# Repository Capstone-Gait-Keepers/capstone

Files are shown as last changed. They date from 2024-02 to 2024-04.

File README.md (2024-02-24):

# Capstone :)

## Folder Structure
- fw: Firmware. Embedded software a.k.a things that run on micros
- data_analysis: All postprocessing or data capturing. Currently includes simulations as well
- datasets: All recorded data
- frontend: Hosts a Vue app
- backend: Hosts a flask App

# Running the Project
## Firmware Setup
1. Add `https://arduino.esp8266.com/stable/package_esp8266com_index.json` as an additional board manager URL (in preferences)
2. Install `esp8266timerinterrupt` library
3. Select NodeMCU 1.0 as the board type
4. Compile and run :)

## Frontend Setup
1. Install [Node](https://nodejs.org/en)
   - Check box to automatically install all dependencies, if applicable 
   - Verify installation with `npm -v`
2. Add `frontend/.env` file (get it from Dan)
3. Install dependencies and run a local development server:
```
cd frontend
npm install
npm run dev
```

## Backend
### Installations
#### Locally hosted Backend
- Python 3.11.6 virtual environment (`python3.11 -m venv ./path/to/venv/folder`)
- Install dependencies in backend_requirements.txt
- `backend/.env` file from cybersecurity risk thread in slack

#### Locally hosted DB
- PostgreSQL https://www.postgresql.org/download/
    - Install with default settings 
- Docker https://docs.docker.com/desktop/install/windows-install/
    - PostgreSQL image 
        - Run 'docker pull postgres' to download the image 
        - Documentation: https://hub.docker.com/_/postgres
- DBeaver https://dbeaver.io/download/
    - or other DB IDE of choice, setup instructions may vary 
    - pgAdmin4 comes with the PostgreSQL installation but I found creating a connection confusing 

### Running the Backend
- If locally hosting the DB, point the `.env` file to the local url
- Run app.py, app will be live locally
- Run client.py in dedicated terminal to test

### Running the Database
#### Docker
- in terminal, run 'docker run --name some-postgres -e POSTGRES_PASSWORD=mysecretpassword -d postgres'
    - name = name of image, your choice
    - password = set a password, remember it preferably
    - 'd' means it runs in 'detached mode'
- To run your image, the command is 'docker start some-postgres' where some-postgres is your image name
- To stop your image, the command is 'docker stop some-postgres'

#### Connecting PostgreSql locally with Docker Image
Make sure your docker image is running first!

Tutorial link that I found helpful: https://www.youtube.com/watch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  (starts from Docker installation)
1. Open DBeaver
2. 'Create new connection' by clicking plug button in top left
3. Select PostgreSQL -> Next
4. Host: localhost
5. Port: 5432
6. Database: postgres
7. password: the password you set with the docker image
8. Click 'Test Connection' -> you should see a success image.
9. If connection works, hit finish

#### FLASK APP
- Run app.py, app will be live locally
- Run client.py in dedicated terminal to test
- Terminal should display success message + data should appear in 'sensors' db table

## Current backend + DB status:
- POST API endpoint set up for testing purposes in Flask app
- PostgreSQL locally hosted on Docker image
- Can receive data from POST endpoint and push it to said database.

### Viewing Frontend Pages from Flask
If you'd like to host the frontend using Flask, you need to build a static version of the frontend.
```
cd frontend
npm run build
```

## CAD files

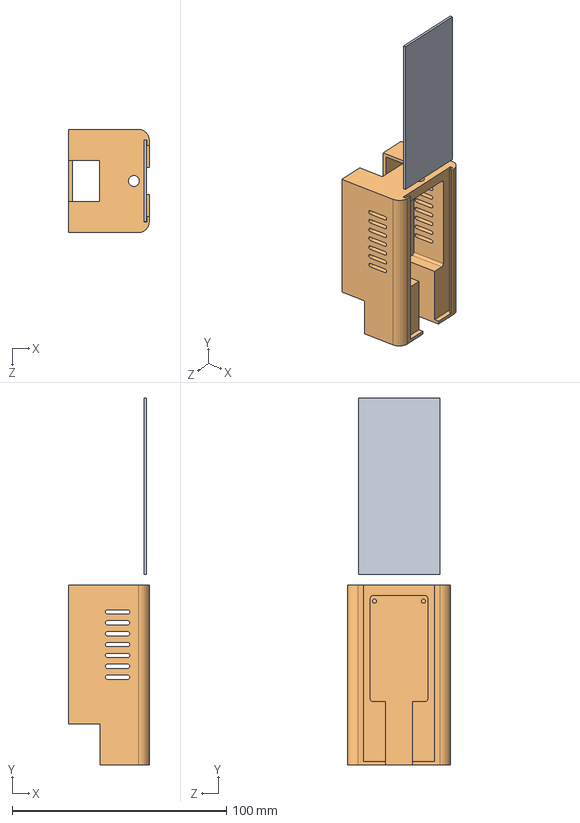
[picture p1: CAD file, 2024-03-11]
casing/Adapter_V2.SLDASM
37.7 x 171.5 x 48.3 mm
Adapter_Case_V2
Adapter_Cover

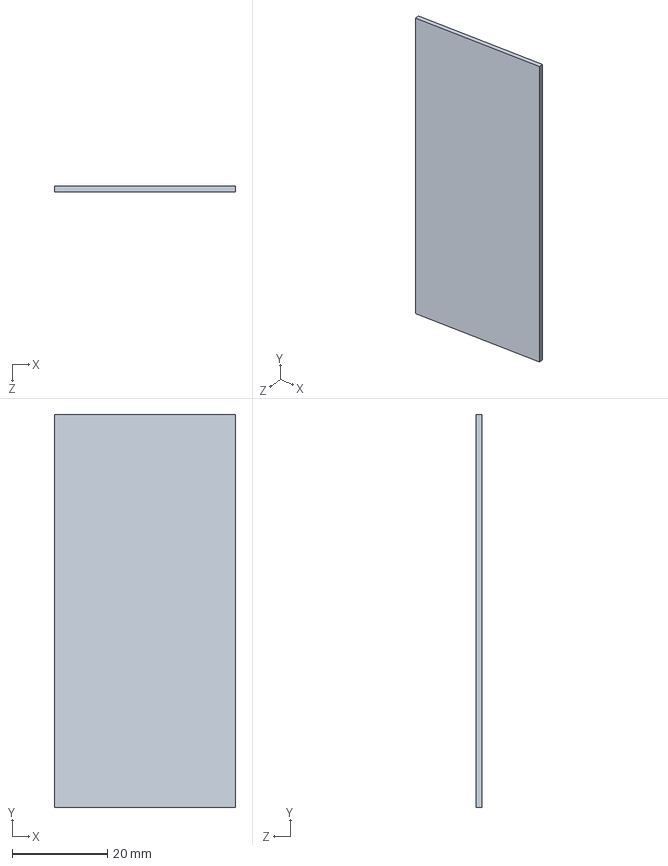
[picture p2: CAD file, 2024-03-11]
casing/Adapter_Cover.SLDPRT
38.1 x 82.5 x 1.27 mm

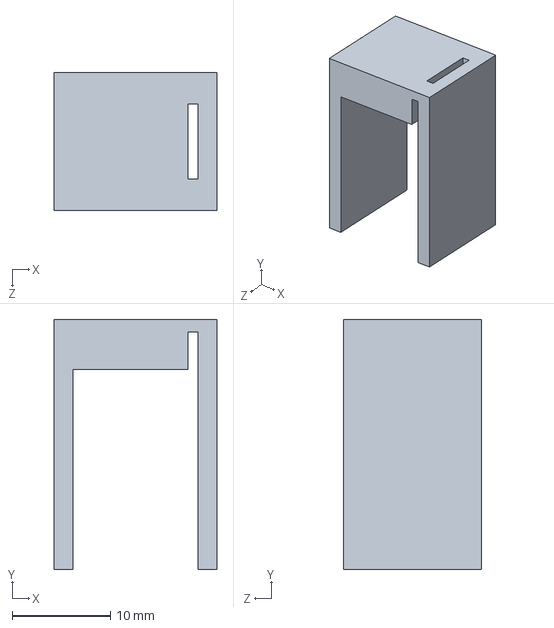
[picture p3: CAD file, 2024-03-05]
casing/V1/Sensor_Case_V1.SLDPRT
16.5 x 25.4 x 14.0 mm

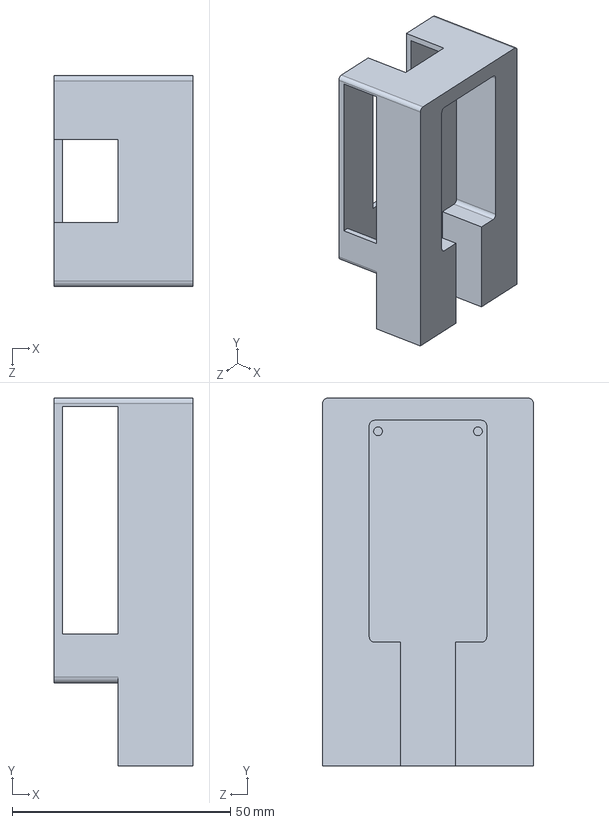
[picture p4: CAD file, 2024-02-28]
casing/V1/Adapter_Case_V1.SLDPRT
31.8 x 84.2 x 48.3 mm

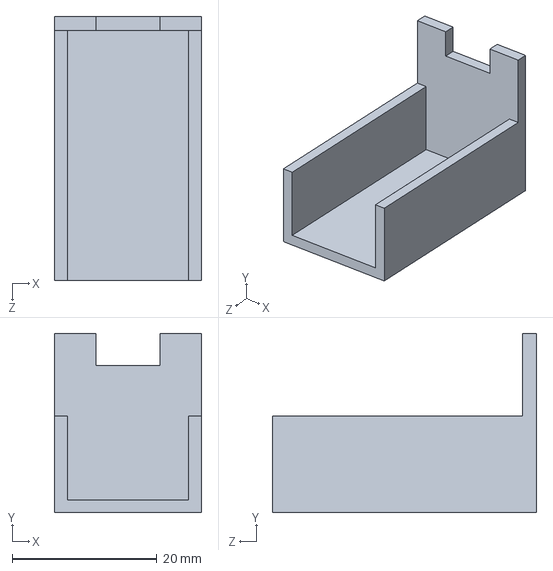
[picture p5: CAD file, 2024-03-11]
casing/Sensor_Cover_V2.SLDPRT
20.3 x 24.8 x 36.4 mm

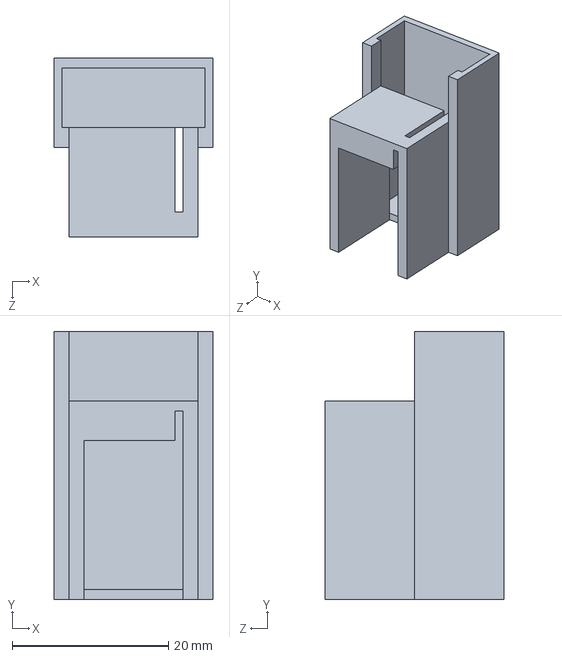
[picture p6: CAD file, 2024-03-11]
casing/Sensor_Case_V2.SLDPRT
20.3 x 34.3 x 22.9 mm

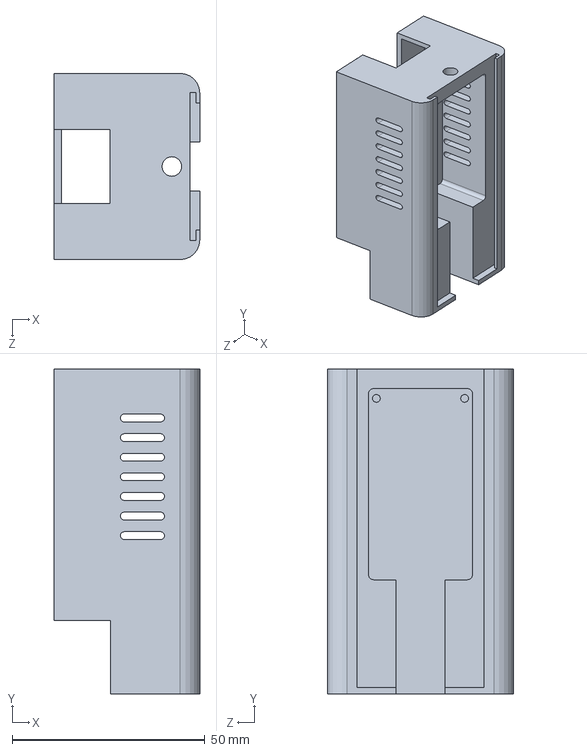
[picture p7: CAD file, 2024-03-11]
casing/Adapter_Case_V2.SLDPRT
37.7 x 84.2 x 48.3 mm

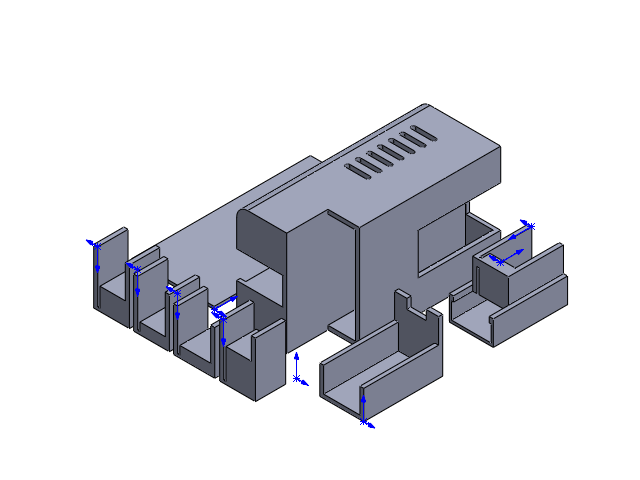
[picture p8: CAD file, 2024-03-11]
casing/V2_Print.SLDASM
Adapter_Cover
Adapter_Case_V2
Sensor_Case_V1_Support0.6
Sensor_Case_V1_Height0.8
Sensor_Case_V1_Height0.9
Sensor_Case_V1_Support0.4
Sensor_Case_V2
Sensor_Cover_V2

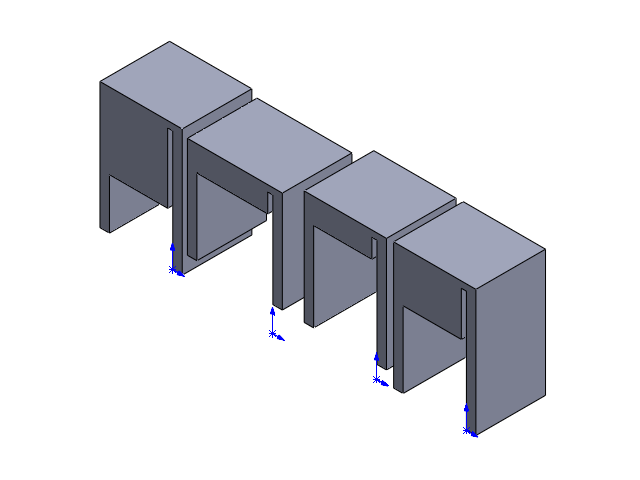
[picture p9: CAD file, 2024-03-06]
casing/SensorCaseVariations.SLDASM
Sensor_Case_V1_Support0.6
Sensor_Case_V1_Height0.8
Sensor_Case_V1_Height0.9
Sensor_Case_V1_Support0.4

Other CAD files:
casing/SensorCaseVariations.STL
casing/Sensor_Cover_V2.STL
casing/V1/Adapter_Case_V1.STL
casing/V1/Sensor_Case_V1.STL
casing/V2_Print.STL

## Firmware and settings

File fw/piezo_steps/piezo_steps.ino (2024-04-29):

#include <Wire.h>
#include <Adafruit_Sensor.h>
#include <Adafruit_BNO055.h>
#include <utility/imumaths.h>
#include "ESP8266TimerInterrupt.h"              //https://github.com/khoih-prog/ESP8266TimerInterrupt

/*
   Connections
   ===========
    Piezo is setup with amplifying circuit:
    Sense wire from piezo to A0 (ADC0)
    Ground
    3v
*/

// Adafruit_BNO055 bno = Adafruit_BNO055(55, 0x28);
ESP8266Timer i_timer;  // Hardware Timer

#define PIEZO_PIN A0 // A0 (ADC0)
#define SAMPLE_RATE 500 // Hz
#define MICROSECONDS 1000000 // Microseconds in a second

#define USER_ID 821094 // User ID for this device

#define INTERRUPT_INTERVAL_US (1000000/SAMPLE_RATE) // Interval between samples in microseconds
#define START_BUFFER_TIME 0.1 // Size of buffer to store acceleration data prior to first step (in seconds)
#define END_BUFFER_TIME 2 // Size of buffer to store acceleration data after last step (in seconds)
#define START_BUFFER_SAMPLES int(START_BUFFER_TIME * SAMPLE_RATE)  // In samples
#define END_BUFFER_SAMPLES END_BUFFER_TIME * SAMPLE_RATE // Number of bad samples to save before stopping saving data
#define CALIBRATION_TIME 6 // Time to run calibration for (in seconds)

// #define AMP_THRESHOLD 0.5 // Threshold for amplitude of acceleration data to be considered "good" (in m/s^2)
float amp_threshold = 0.03; // Threshold for amplitude of acceleration data to be considered "good" (in m/s^2)

volatile bool start_sampling = false; // Flag to indicate if a new sample should be taken based on timer interrupt

bool calibration_flag = false; // Flag to indicate if the device is in calibration mode
bool wifi_status = false; // Flag to indicate if the device is connected to wifi

float sensor_data_buffer[START_BUFFER_SAMPLES]; // Circular buffer to store acceleration data
int start_buffer_index = 0; // Index of circular buffer
String post_data = ""; // String to store data to be sent to backend server
bool save_sample_flag = false; // Flag to indicate if a sample should be saved to post_data
bool post_data_ready = false; // Flag to indicate if post_data is ready to be sent to backend server
int end_buffer_length = 0; // Counter to logic to stop saving data to post_data if too many bad samples are received
bool good_sample = false; // Flag to indicate if a sample is considered "good" (above threshold)


// Interrupt handler for timer
void ICACHE_RAM_ATTR TimerHandler(void)
{
  if (start_sampling) {
    Serial.println("ERROR: PREVIOUS SAMPLED WAS NOT FINISHED");
  }
  start_sampling = true;
}

void update_circular_buffer(float accel_z) {
  // Update circular buffer
  sensor_data_buffer[start_buffer_index] = accel_z;
  good_sample = abs(accel_z) > amp_threshold;
  start_buffer_index++;
  start_buffer_index %= START_BUFFER_SAMPLES; 
  // Move to the next index, modulus handle wraparound
}

void save_circular_buffer() {
  Serial.println("Begin saving data");
  post_data += "{\"sensorid\":\"" + String(USER_ID) + "\",\"ts_data\":[";
  for (int i = start_buffer_index; i < start_buffer_index + START_BUFFER_SAMPLES; i++) {
      post_data += String(sensor_data_buffer[i % START_BUFFER_SAMPLES]) + ",";
  }
  save_sample_flag = true;
}
void save_sample(float accel_z) {
  post_data += String(accel_z) + ",";
}

void stop_saving_samples() {
  save_sample_flag = false;
  post_data_ready = true;
  end_buffer_length = 0;
}

void running_mode() {
  if (start_sampling) 
  {
    float accel_z = getVerticalAcceleration(); // Get z component of acceleration
    start_sampling = false; // Reset flag for interrupt handler

    update_circular_buffer(accel_z); // Update circular buffer with new sample
    // if sample is considered good (above threshold), save buffer to string and start saving data to post_data
    if (good_sample && !save_sample_flag) {
      save_circular_buffer();
      led_on();
    }
    if (good_sample && save_sample_flag) {
      save_sample(accel_z);
      end_buffer_length = 0;
    }
    if (!good_sample && save_sample_flag) {
        if (end_buffer_length < END_BUFFER_SAMPLES) {
          save_sample(accel_z);
          end_buffer_length++;
        } 
        else {
          stop_saving_samples(); // Stop saving samples & reset flags if too many samples don't meet threshold
        }
      }
    if (post_data_ready) {
        Serial.println("POST DATA READY:");
        i_timer.disableTimer();
        led_off();
        // remove last comma if it exists
        if (post_data.endsWith(",")) {
          post_data.remove(post_data.length() - 1);
        }
        post_data += "]}";  // add the end of the json format
        send_data(&post_data);
        post_data_ready = false;
        post_data = "";
        i_timer.enableTimer();
    }
  }
}

double getVerticalAcceleration() {
  int sensorValue = analogRead(PIEZO_PIN);
  double voltage = sensorValue * (3.3 / 1023.0);
  double acceleration = (voltage - 2.04); // account for DC offset (manual)
  return acceleration;
}


void setup(void)
{
  Serial.begin(115200);
  delay(100);
  Serial.println("FW: Step Detection\n");

  pinMode(LED_BUILTIN, OUTPUT);     // Initialize the LED_BUILTIN pin as an output
  pinMode(PIEZO_PIN, INPUT);
  digitalWrite(LED_BUILTIN, HIGH);   // Turn the LED on by making the voltage LOW
  wifi_status = initialize_wifi();

  Serial.print("Sample Rate (Hz): ");
  Serial.println(SAMPLE_RATE);
  i_timer.attachInterruptInterval(INTERRUPT_INTERVAL_US, TimerHandler);
  i_timer.enableTimer();
}

void loop(void)
{
  if (!wifi_status) {
    sos_mode();
  }
  if (calibration_flag) {
    calibration_mode();
  }
  else {
    running_mode();
  }
}

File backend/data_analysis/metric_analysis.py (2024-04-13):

import numpy as np
import pandas as pd
import plotly.express as px
import sys
from plotly.subplots import make_subplots
from plotly import graph_objects as go
from typing import List, Tuple, Optional, Iterable
from logging import Logger, getLogger, StreamHandler, FileHandler, Formatter

from data_types import Recording, RecordingEnvironment, SensorType, get_optimal_analysis_params
from metrics import Metrics
from step_detection import DataHandler, StepDetector, TimeSeriesProcessor


class RecordingProcessor:
    """Collection of methods for processing recordings"""
    def __init__(self) -> None: ...

    @staticmethod
    def get_steps_from_truth(rec: Recording, step_duration=0.4, shift_percent=0.2, align_peak=True, plot=False) -> List[np.ndarray]:
        """
        Uses the source of truth to parse the accelerometer data pertaining to steps
        """
        proc = TimeSeriesProcessor(rec.env.fs)
        offset = int(shift_percent * rec.env.fs / 2)
        window_size = proc.timestamp_to_index(step_duration)
        step_measurements = []
        for event in rec.events:
            if event.category == 'step':
                start = max(0, proc.timestamp_to_index(event.timestamp) - offset)
                step_data = rec.ts[start : start+window_size]
                if len(step_data) != window_size:
                    raise ValueError(f"Step data is the wrong size: {len(step_data)} != {window_size} ({len(rec.ts)=}, {start=}, {start+window_size=})")
                if align_peak:
                    energy = proc.get_energy(step_data, step_duration / 5)
                    start += np.argmax(energy) - offset
                    step_data = rec.ts[start : start+window_size]
                if start + window_size > len(rec.ts):
                    continue
                if len(step_data) != window_size:
                    raise ValueError(f"Step data is the wrong size: {len(step_data)} != {window_size}")
                step_measurements.append(step_data)
        if plot:
            fig = go.Figure()
            fig.update_layout(title="Step Data")
            timestamps = np.linspace(0, step_duration, len(step_measurements[0]))
            for step in step_measurements:
                fig.add_scatter(x=timestamps, y=proc.get_energy(step, step_duration/2))
            fig.show()
        return step_measurements

    @staticmethod
    def get_noise(rec: Recording, window_duration=0.2, plot=False) -> np.ndarray:
        """
        Find the noise floor of the accelerometer data
        """
        if len(rec.events) == 0:
            return rec.ts
        proc = TimeSeriesProcessor(rec.env.fs)
        first_event = rec.events[0].timestamp - window_duration
        noise = rec.ts[:proc.timestamp_to_index(first_event)]
        if plot:
            timestamps = np.linspace(0, len(noise) / rec.fs, len(noise))
            fig = go.Figure()
            fig.update_layout(title="Noise", showlegend=False)
            fig.add_scatter(x=timestamps, y=noise)
            fig.show()
        return noise

    @staticmethod
    def get_frequency_weights(rec: Recording, window_duration=0.2, plot=False) -> Tuple[np.ndarray, np.ndarray]:
        """
        Find the dominant frequencies pertaining to steps
        """
        proc = TimeSeriesProcessor(rec.env.fs)
        step_data = RecordingProcessor.get_steps_from_truth(rec, window_duration*2, align_peak=True, plot=plot)
        freqs = proc.get_window_fft_freqs(window_duration)
        amp_per_step_freq_time = []

        for step in step_data:
            if not len(step):
                raise ValueError(f"Step data is empty: {step_data}")
            amps = proc.rolling_window_fft(step, window_duration, stride=1, ignore_dc=True)
            amp_per_step_freq_time.append(amps)
        amp_per_step_freq_time = np.asarray(amp_per_step_freq_time)
        amp_per_step_freq = np.mean(amp_per_step_freq_time, axis=-1)
        amp_per_freq = np.mean(amp_per_step_freq, axis=0)

        noise_amp_per_freq = RecordingProcessor.get_noise_frequency_weights(rec, window_duration, plot=plot)
        freq_weights = amp_per_freq / noise_amp_per_freq
        freq_weights /= np.max(freq_weights)

        if plot:
            timestamps = np.linspace(0, window_duration, len(amp_per_step_freq_time[0]))
            num_rows = int(np.ceil(np.sqrt(len(step_data))))
            fig = make_subplots(rows=num_rows, cols=num_rows, column_titles=['Step Heat Maps (Freq vs Time)'])
            for i, amps in enumerate(amp_per_step_freq_time, start=1):
                fig.add_heatmap(x=timestamps, y=freqs, z=amps, row=(i // num_rows) + 1, col=(i % num_rows) + 1)
            fig.show()
            fig = go.Figure()
            fig.update_layout(title="Amplitude vs Frequency For Each Step", showlegend=False)
            for step_amp_per_freq in amp_per_step_freq:
                fig.add_scatter(x=freqs, y=step_amp_per_freq)
            fig.show()
            fig = go.Figure()
            fig.update_layout(title="Amplitude vs Frequency (Average of all steps)", showlegend=False)
            fig.add_scatter(x=freqs, y=freq_weights)
            fig.show()
        return freq_weights

    @staticmethod
    def get_noise_frequency_weights(rec: Recording, window_duration=0.2, plot=False) -> np.ndarray:
        """Creates a model of noise frequency weights, ranging from 0 to 1, where 1 is the strongest frequency component of the noise floor"""
        proc = TimeSeriesProcessor(rec.env.fs)
        noise = RecordingProcessor.get_noise(rec, window_duration)
        noise_amp_per_freq_time = proc.rolling_window_fft(noise, window_duration, stride=1, ignore_dc=True)
        noise_amp_per_freq = np.mean(noise_amp_per_freq_time, axis=-1)
        noise_amp_per_freq /= np.max(noise_amp_per_freq)
        if plot:
            freqs = proc.get_window_fft_freqs(window_duration)
            fig = px.scatter(x=freqs, y=noise_amp_per_freq, title="Noise Amplitude vs Frequency")
            fig.show()
        return noise_amp_per_freq
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

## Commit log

2023-10-11 sample data
    [sample walk.csv]
2023-10-11 data collection file
    [fun.csv, sample walk.csv]
2023-10-11 deleted bad file
    [sample walk.csv]
2023-10-13 Restructured repo, added Daniel's fw
    [sample walk.csv]
2023-10-15 Updated sample rate
2023-10-15 added various walking measurements to dataset
    [Lychee Fast Living Room Hardwood.csv, Lychee Regular Living Room Hardwood.csv, Ron Regular Basement Laminate.csv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]
2023-10-19 Fixed datasets
    [Ron Regular Basement Laminate.csv, Ron Slow Basement Laminate.csv, Ron and Lychee Living Room.csv]
2023-10-25 Added button and resolved comments from first commit
    [data_capture.py]
2023-10-27 addressed comments for commit 2: var names, throwing error
    [data_capture.py]
2023-10-29 Moved yamls to archive
    [Lychee Fast Living Room Hardwood.csv, Lychee Regular Living Room Hardwood.csv, Ron Regular Basement Laminate.csv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]
2023-10-30 Added noise floor estimation
    [data_types.py, step_detection.py]
2023-10-30 Fixed frequency weighting, added cadence
    [step_detection.py]
2023-10-30 Added std of measurement error
    [step_detection.py]
2023-11-18 Padded rolling window, fixed step modelling
    [step_detection.py]
2023-11-21 working on wifi, error -1, sol tbd
    [wifi_connect.ino]
2023-11-23 Added curl request comments + was missing brackets oops
    [app.py]
2023-11-24 Attempting to fix sensor_metadata
    [app.py]
2023-11-24 test 1 success, still pinging too much
    [wifi_connect.ino]
2023-11-24 TEST 4 BABY, still sending too many times. fix later
    [wifi_connect.ino]
2023-11-25 Fixed sensor_metadata (hopefully)
2023-11-27 Pretty printing error
2023-12-14 running and calibration mode added
2023-12-14 added interrupt logic to calibration mode
2023-12-14 wifi initialization with sos led indicator
2023-12-14 send sensor data successfully only the first time
2023-12-15 calibration works, still sending fake data due to database limit
2023-12-15 updated calibration with LED working
2023-12-15 added constants and LED SOS modes
2023-12-15 Setting some sensor values to nullable
2023-12-23 pool_pre_ping=True clause to help fix rollback errors
    [app.py]
2024-01-19 Updating code to match new connection string- missed in last push
    [app.py]
2024-01-20 Attempting to fix cycleops error, pings the database before sending recording
    [app.py]
2024-01-24 attempting to communicate with local backend (unicode error)
    [serial_bridge.py, wifi.ino]
2024-01-25 Error handling update - moved return statements
    [app.py]
2024-01-25 Fixing error message output:
    [app.py]
2024-01-25 Fixing some output statements - otherwise all good
    [app.py]
2024-01-25 Fixing finally statements, adding same OperationalError handling to add_sensorconfig
    [app.py]
2024-01-31 local dev working with delimeter error on second send attempt
    [app.py, bno055_steps.ino, serial_bridge.py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]
2024-02-04 Error handling to work for more datasets
    [step_detection.py]
2024-02-05 fixed critical json data error
    [bno055_steps.ino, serial_bridge.py]
2024-02-05 Fixed np mean nan warning
    [data_types.py]
2024-02-08 Fixed optimization (actually calculates error)
    [metric_analysis.py, optimize.py]
2024-02-09 Fixed unconfirmed step error, added debug statements
    [step_detection.py]
2024-02-10 Fixed step delta enforcement, added back optimization constraints
    [data_types.py, metric_analysis.py, optimize.py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]
2024-02-12 Fixed bouncing button source
    [data_types.py, step_detection.py]
2024-02-12 Manually fixed bad button presses
2024-02-17 Started diagnosis weights issue
    [metric_analysis.py, step_detection.py]
2024-02-20 Added folder filtering, updated commands
2024-02-21 Add tangent calc, fixed default coefs
    [data_types.py, metric_analysis.py, step_detection.py]
2024-02-24 Adding print statements for some quick performance testing
2024-02-25 Created backend-side RLS for receiving sensor data. Checks to see if received sensorid matches a configured sensor in new_sensor table, and allows the data to the database if so. Returns error if not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
    [app.py]
2024-02-25 C:/Program Files/Git/api/send_recording will check that sensorid sent by sensor matches an entry in new_sensor table. Acting as a form of RLS to prevent random/public writes to the table. Also helps 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
    [app.py]
2024-02-26 Seamless sensor switching, accounting for no correct steps
    [data_capture.py, data_types.py, metric_analysis.py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]
2024-02-26 Fixed numpy warning, added lazy loading
    [data_types.py, metric_analysis.py]
2024-02-26 Added metric error function
    [data_types.py, metric_analysis.py, optimize.py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]
2024-02-28 v1 casing
    [Adapter_Case_V1.SLDPRT, Adapter_Case_V1.STL]
2024-02-28 added folder for casing
    [Adapter_Case_V1.SLDPRT, Adapter_Case_V1.STL]
2024-02-29 Corrected FPR & FNR to be per recording
    [metric_analysis.py]
2024-03-03 Corrected fft padding, added min signal log
    [step_detection.py]
2024-03-03 Analyzed piezo wire, correct false rates
    [metric_analysis.py]
2024-03-03 Fixed signal power calculations
    [metric_analysis.py, step_detection.py]
2024-03-04 Attempted piezo optimization with classification rates (doesn't work)
    [data_types.py, metric_analysis.py, optimize.py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]
2024-03-05 get_user endpoint in progress - DB connection broken
    [frontend_integration.py]
2024-03-05 Updated FakeUser and NewSensor class to fix back_populate
    [database.py]
2024-03-05 added sensor case v1
    [Sensor_Case_V1.SLDPRT, Sensor_Case_V1.STL]
2024-03-06 Added sensor case variations
    [SensorCaseVariations.SLDASM, SensorCaseVariations.STL]
2024-03-06 C:/Program Files/Git/api/create_user works locally. Updated FakeUser class to allow nullable sensorid to make our lives easier if demoing the whole flow without a real sensorid. If ID is improperly e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
    [database.py, frontend_integration.py]
2024-03-10 C:/Program Files/Git/api/create_user only allows configured sensorids
2024-03-10 Removing old sensor and test class db code
2024-03-10 C:/Program Files/Git/api/create_user only allows entries with unique sensorid
2024-03-11 All V2 files
    [Adapter_Case_V2.SLDPRT, Adapter_Cover.SLDPRT, Adapter_V2.SLDASM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]
2024-03-12 reorganized casing folder
    [Adapter_Case_V1.SLDPRT, Adapter_Case_V1.STL, Sensor_Case_V1.SLDPRT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]
2024-03-13 Handoff to Daniel - data_analysis errors
    [data_types.py, frontend_integration.py, metric_analysis.py]
2024-03-13 Added switches
2024-03-13 Fixed sensor id naming
2024-03-14 Fixed switches
2024-03-15 created piezo main fw (problems exist)
    [calibration.ino, data_capture.py, piezo_steps.ino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]
2024-03-16 Fully connected traces
2024-03-16 symposium bridge working with memory issues (need to fix)
    [data_capture.py, piezo_steps.ino, symposium_bridge.py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]
2024-03-18 Low buttons, settings background
2024-03-18 Fixed data handler plotting
    [step_detection.py]
2024-03-19 updated sensor cover with bigger wire opening
    [Sensor_Cover_V2.STL]
2024-04-10 Updated performance testing print statements + added time measurement to frontend_integration.py signals stuff
2024-04-11 Added error options, allowed step groups of 2
    [data_types.py, metric_analysis.py, step_detection.py]
